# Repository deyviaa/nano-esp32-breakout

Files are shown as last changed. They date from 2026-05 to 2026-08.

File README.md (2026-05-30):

# 🛠️ ArdNanoESP32 DevBoard

> *A compact, feature-packed carrier board for the Arduino Nano ESP32 — bridging the gap between bare breadboard chaos and a polished development kit.*

---

## 📖 Overview

This project is a custom-designed **PCB carrier board** built around the **Arduino Nano ESP32** (dual-core Xtensa LX7, Wi-Fi + BLE). Sized to an approximate **iPhone footprint**, the board is designed as an intermediate prototyping platform with a philosophy of **hardware-level safety** ("student-proofing") — all peripherals are wired with protection resistors, clean logic states, and deliberate design choices baked in at the schematic level.

The board seats the Nano ESP32 in ZIF-style socket headers and exposes every GPIO to parallel jumper pin headers for external breadboard connectivity, while also integrating a full suite of on-board peripherals ready for immediate use.

**Current Status:**

```
✅ Schematic design — Complete & verified
✅ Component footprints — All assigned & resolved
✅ Git version control — Initialized (cross-platform)
🔄 PCB Layout & Routing — In Progress
⬜ Gerber Generation & Fab — Pending
⬜ Assembly & Bring-up — Pending
```

---

## ⚡ Power Architecture

The board runs two accessible power rails sourced from the Nano ESP32's onboard regulators:

| Rail | Source | Purpose |
|---|---|---|
| **5V** | `VUSB` | WS2812B LED, raw power header |
| **3.3V** | Nano onboard LDO | All logic peripherals, GPIO I/O, I2C bus |
| **GND** | Common ground | Shared reference for all rails |

All power rails are broken out to dedicated 4-pin headers on the board edge for external use.

---

## 🧩 Peripheral Map

```
┌─────────────────────────────────────────────────────────┐
│               Arduino Nano ESP32 Carrier Board           │
│                                                         │
│  ┌──────────────┐     ┌─────────────┐                   │
│  │ Nano ESP32   │     │  4x LEDs    │ ── 1kΩ CLR ── GPIO │
│  │  (socketed)  │     │  4x Buttons │ ── 10kΩ PD ── GPIO │
│  └──────────────┘     │  4x Switches│ ── 1kΩ SER ── GPIO │
│                        └─────────────┘                   │
│  ┌──────────────┐     ┌─────────────┐                   │
│  │  WS2812B     │     │  Qwiic/     │                   │
│  │  RGB LED     │     │  STEMMA QT  │ ── SDA(A4)/SCL(A5) │
│  │  (5V + 470Ω) │     │  JST-SH 4P  │ ── 4.7kΩ pull-ups  │
│  └──────────────┘     └─────────────┘                   │
│  ┌──────────────┐     ┌─────────────┐                   │
│  │  Alps RK09K  │     │  12mm Piezo │                   │
│  │  Rotary Pot  │     │  Buzzer     │ ── SW mute ── GPIO  │
│  │  (VDiv/A0)   │     │  (220Ω buf) │                   │
│  └──────────────┘     └─────────────┘                   │
└─────────────────────────────────────────────────────────┘
```

---

## 🔌 Peripheral Specifications

### 💡 LEDs × 4
- Generic standard LEDs, **active-high**
- **1kΩ** current-limiting resistors in series
- Clean GPIO drive, no floating states

### 🔘 Push Buttons × 4
- Momentary tactile switches
- **10kΩ pull-down** resistors → guaranteed `LOW` at rest
- No debounce hardware (handle in firmware or use `INPUT_PULLUP`)

### 🎚️ Slide Switches × 4 (Stateful GPIO Inputs)
- **SS12D00G-G3** SPDT Slide Switches (2.54mm pitch)
- Hard-wired: Pin 1 → 3.3V, Pin 3 → GND, Pin 2 → MCU
- **1kΩ series resistor** between common and GPIO — prevents a dead short if pin is accidentally configured as `OUTPUT LOW`
- ⚠️ *Avoid routing these to ESP32 strapping pins (GPIO0, GPIO3, GPIO45, GPIO46)*

### 🌈 WS2812B Addressable RGB LED
- **5050** form factor, driven from **VUSB (5V)** rail
- **100nF decoupling cap** placed physically adjacent to VDD/GND
- Data driven by 3.3V GPIO through **470Ω series resistor** (signal protection + level tolerance)
- `DOUT` left unconnected — ready for future LED chain expansion

### 🔁 Qwiic / STEMMA QT Connector (I2C)
- **JST-SH SM04B-SRSS-TB**, 1.0mm pitch, 4-pin
- Industry-standard pinout: `GND | 3V3 | SDA | SCL`
- Routed to hardware I2C: **SDA → A4**, **SCL → A5**
- **Two 4.7kΩ pull-up resistors** on SDA and SCL to 3.3V (open-drain compliant)
- Compatible with the entire Sparkfun/Adafruit Qwiic/STEMMA QT ecosystem

### 🎛️ Rotary Potentiometer
- **Alps RK09K** 9mm single-gang
- Wired as a safe voltage divider: Pin 1 → 3.3V, Pin 3 → GND, Wiper → Analog GPIO (A0–A7)
- Footprint includes 2 mechanical snap-in anchor pads for PCB stability

### 🔊 Piezo Buzzer
- **12mm PCB-mount** piezo, standard 7.62mm through-hole pitch
- **220Ω buffer resistor** on signal line
- **Hardware mute switch** (SS12D00 SPDT): one throw connects signal → buzzer positive; mute position leaves the throw floating (no drain-to-GND waste)

---

## 🗂️ Schematic Hierarchy

The project uses a hierarchical schematic structure in KiCad (4 sheets):

| Sheet | File | Contents |
|---|---|---|
| `/` | `ArdNanoESP32_DevBoard.kicad_sch` | Top-level hierarchy |
| `/MCU_Pins_Sockets/` | `MCU_Pins_Sockets.kicad_sch` | Nano ESP32 socket + jumper headers |
| `/PowerRails/` | `PowerRails.kicad_sch` | VUSB, 3V3, GND breakout headers |
| `/Peripherals/` | `Peripherals.kicad_sch` | All on-board peripherals |

---

## 🔧 KiCad Footprint Notes & Resolutions

Several non-obvious footprint decisions were made to match real-world, off-the-shelf components:

| Component | Footprint Assigned | Reason |
|---|---|---|
| SS12D00G-G3 Switches | `PinHeader_1x03_P2.54mm_Vertical` | Amazon-sourced units have **2.54mm pitch** (not standard 2mm) |
| Slide Switch Symbol | Generic `SW_SPDT` | Replaced Wuerth proprietary symbol — Pin 2 must be common to prevent 3V3↔GND short |
| JST-SH I2C Connector | `JST_SH_SM04B-SRSS-TB_1x04-1MP_P1.00mm_Horizontal` | Standard Qwiic/STEMMA 1.0mm pitch |
| Piezo Buzzer | `Buzzer_12x9.5mm_CR2032_Vertical` | Matches 7.62mm THT pin spacing |
| Alps Potentiometer | `Potentiometer_Alps_RK09K_Single_Vertical` | 3 signal pins + 2 mechanical anchor pads |
| Resistors (THT) | `R_Axial_DIN0207_L6.3mm_D2.5mm_P10.16mm_Horizontal` | Matches physical inventory |
| Resistors (SMD) | `R_0603_1608Metric_Pad1.05x0.95mm_HandSolder` | Hand-solder pad relief |

---

## 🌿 Git Workflow & Version Control

The repo is structured for **cross-platform KiCad development** (Windows PC ↔ MacBook Air).

### `.gitignore` covers:
```
# KiCad auto-generated / user-specific files
*.kicad_prl        # Per-user UI layout state
fp-info-cache      # Local footprint cache (rebuilt automatically)
*-bak              # KiCad backup files
*.lck              # Lock files (open-file indicators)
*_autosave-*       # Crash recovery autosaves
```

### ⚠️ Critical Workflow Rule

KiCad `.kicad_sch` and `.kicad_pcb` files are **binary-adjacent** — they do not merge cleanly. Follow this loop **strictly**:

```
┌─────────────────────────────────────────────┐
│                                             │
│   1. git pull  ← ALWAYS before opening     │
│   2. Open KiCad & do work                  │
│   3. Close KiCad (flushes file writes)     │
│   4. git add / commit / push               │
│                                             │
│   ❌ Never leave files open across machines │
│   ❌ Never commit while KiCad is open       │
│                                             │
└─────────────────────────────────────────────┘
```

---

## 🧰 Tools & Software

| Tool | Version | Purpose |
|---|---|---|
| **KiCad** | 8.0.x | Schematic capture & PCB layout |
| **Git** | Any | Version control |
| **Arduino IDE / PlatformIO** | Latest | Firmware development |

---

## 📐 Design Constraints

- **Target Form Factor:** ~iPhone footprint (≈ 71mm × 150mm)
- **MCU:** Arduino Nano ESP32 (seated, not soldered)
- **Logic Level:** 3.3V throughout
- **Power Input:** USB via Nano ESP32 onboard USB-C

---

## 🚧 Roadmap

- [x] Schematic capture (all 4 sheets)
- [x] ERC pass — no errors
- [x] Footprint assignment & verification
- [x] Git repo initialization + `.gitignore`
- [ ] PCB layout — component placement
- [ ] PCB routing — all nets
- [ ] DRC pass — no errors
- [ ] 3D model review
- [ ] Gerber generation
- [ ] PCB fabrication (JLCPCB / PCBWay)
- [ ] Board bring-up & hardware testing
- [ ] Firmware examples / demo sketches

---

## 📄 License

*To be determined.*

---

> *Designed in KiCad. Iterated on breadboards. Built to survive students.*

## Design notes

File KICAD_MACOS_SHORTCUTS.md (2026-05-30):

# KiCad macOS Shortcuts

A comprehensive and organized list of macOS shortcuts and commands for KiCad, broken down by application module.

## 3D Viewer

| Context | Action | Shortcut |
|---|---|---|
| Control | 3 D Viewer. Control |  |
| Control | Attribute Dnp | D |
| Control | Attribute Not In Posfile | P |
| Control | Attributes Other | V |
| Control | Attributes S M D | S |
| Control | Attributes T H T | T |
| Control | Copy To Clipboard |  |
| Control | Export Image |  |
| Control | Flip View | F |
| Control | Home View | Home |
| Control | Material C A D |  |
| Control | Material Diffuse |  |
| Control | Material Normal |  |
| Control | Move Down | Down |
| Control | Move Left | Left |
| Control | Move Right | Right |
| Control | Move Up | Up |
| Control | No Grid |  |
| Control | Pivot Center | Space |
| Control | Reload Board |  |
| Control | Rotate Xclockwise |  |
| Control | Rotate Xcounterclockwise |  |
| Control | Rotate Yclockwise |  |
| Control | Rotate Ycounterclockwise |  |
| Control | Rotate Zclockwise | Shift+R |
| Control | Rotate Zcounterclockwise | R |
| Control | Show10Mm Grid |  |
| Control | Show1Mm Grid |  |
| Control | Show2 5Mm Grid |  |
| Control | Show5Mm Grid |  |
| Control | Show Bounding Boxes |  |
| Control | Show Layers Manager |  |
| Control | Show Navigator |  |
| Control | Toggle Ortho |  |
| Control | Toggle Raytacing |  |
| Control | View Back | Shift+Y |
| Control | View Bottom | Shift+Z |
| Control | View Front | Y |
| Control | View Left | Shift+X |
| Control | View Right | X |
| Control | View Top | Z |

## Common Shortcuts

| Context | Action | Shortcut |
|---|---|---|
| API | Plugins Reload |  |
| Checker | Exclude Marker |  |
| Checker | Next Marker |  |
| Checker | Prev Marker |  |
| Control | Activate Point Editor |  |
| Control | Add Library |  |
| Control | Center Contents |  |
| Control | Center Justify |  |
| Control | Center Selection |  |
| Control | Collapse All |  |
| Control | Cursor45 Crosshairs |  |
| Control | Cursor Click | Return |
| Control | Cursor Dbl Click | End |
| Control | Cursor Down | Down |
| Control | Cursor Down Fast | Cmd+Down |
| Control | Cursor Full Crosshairs |  |
| Control | Cursor Left | Left |
| Control | Cursor Left Fast | Cmd+Left |
| Control | Cursor Right | Right |
| Control | Cursor Right Fast | Cmd+Right |
| Control | Cursor Small Crosshairs |  |
| Control | Cursor Up | Up |
| Control | Cursor Up Fast | Cmd+Up |
| Control | Ddadd Library |  |
| Control | Edit Grid Origin |  |
| Control | Edit Grids |  |
| Control | Expand All |  |
| Control | Grid Fast1 | Option+1 |
| Control | Grid Fast2 | Option+2 |
| Control | Grid Fast Cycle | Option+4 |
| Control | Grid Next | N |
| Control | Grid Preset |  |
| Control | Grid Prev | Shift+N |
| Control | Grid Reset Origin |  |
| Control | Grid Set Origin |  |
| Control | Hide Library Tree |  |
| Control | High Contrast Mode |  |
| Control | High Contrast Mode Cycle | H |
| Control | Imperial Units |  |
| Control | Left Justify |  |
| Control | Library Tree Search | Cmd+L |
| Control | Magnetic Snap Active Layer |  |
| Control | Magnetic Snap All Layers |  |
| Control | Magnetic Snap Toggle | Shift+S |
| Control | Metric Units |  |
| Control | Mils |  |
| Control | New | Cmd+N |
| Control | New Library |  |
| Control | Open | Cmd+O |
| Control | Open Directory |  |
| Control | Open With Text Editor |  |
| Control | Page Settings |  |
| Control | Pan Down | Shift+Down |
| Control | Pan Left | Shift+Left |
| Control | Pan Right | Shift+Right |
| Control | Pan Up | Shift+Up |
| Control | Pin Library |  |
| Control | Plot |  |
| Control | Print | Cmd+P |
| Control | Quit |  |
| Control | Redo Zoom |  |
| Control | Refresh Preview |  |
| Control | Reset Local Coords | Space |
| Control | Revert |  |
| Control | Right Justify |  |
| Control | Save | Cmd+S |
| Control | Save All |  |
| Control | Save As | Cmd+Shift+S |
| Control | Save Copy |  |
| Control | Select Columns |  |
| Control | Show3 D Viewer | Option+3 |
| Control | Show Calculator Tools |  |
| Control | Show Context Menu |  |
| Control | Show Datasheet | D |
| Control | Show Footprint Browser |  |
| Control | Show Footprint Editor |  |
| Control | Show Library Tree |  |
| Control | Show Project Manager |  |
| Control | Show Properties |  |
| Control | Show Symbol Browser |  |
| Control | Show Symbol Editor |  |
| Control | Toggle Bounding Boxes |  |
| Control | Toggle Cursor |  |
| Control | Toggle Grid |  |
| Control | Toggle Grid Overrides | Cmd+Shift+G |
| Control | Toggle Polar Coords |  |
| Control | Toggle Units | Cmd+U |
| Control | Undo Zoom |  |
| Control | Unpin Library |  |
| Control | Update Find |  |
| Control | Update Pcb From Schematic | F8 |
| Control | Update Preferences |  |
| Control | Update Schematic From P C B |  |
| Control | Update Units |  |
| Control | Zoom Center | F4 |
| Control | Zoom Fit Objects | Cmd+Home |
| Control | Zoom Fit Screen | Cmd+0 |
| Control | Zoom Fit Selection |  |
| Control | Zoom In | Cmd++ |
| Control | Zoom In Center |  |
| Control | Zoom In Horizontally |  |
| Control | Zoom In Vertically |  |
| Control | Zoom Out | Cmd+- |
| Control | Zoom Out Center |  |
| Control | Zoom Out Horizontally |  |
| Control | Zoom Out Vertically |  |
| Control | Zoom Preset |  |
| Control | Zoom Redraw | Cmd+R |
| Control | Zoom Tool | Cmd+F5 |
| Embed | Embeded File |  |
| Embed | Extract File |  |
| Embed | Remove File |  |
| Groups | Group Properties |  |
| Groups | Select New Group Member |  |
| Interactive | Add To Group |  |
| Interactive | Cancel |  |
| Interactive | Copy | Cmd+C |
| Interactive | Copy As Text | Cmd+Shift+C |
| Interactive | Cut | Cmd+X |
| Interactive | Cycle Arc Edit Mode | Cmd+Space |
| Interactive | Delete | Back |
| Interactive | Delete Tool |  |
| Interactive | Duplicate | Cmd+D |
| Interactive | Find | Cmd+F |
| Interactive | Find And Replace | Cmd+Option+F |
| Interactive | Find Next | F3 |
| Interactive | Find Next Marker | Cmd+Shift+F3 |
| Interactive | Find Previous | Shift+F3 |
| Interactive | Finish | End |
| Interactive | Group |  |
| Interactive | Group Enter |  |
| Interactive | Group Leave |  |
| Interactive | Measure Tool | Cmd+Shift+M |
| Interactive | Paste | Cmd+V |
| Interactive | Paste Special | Cmd+Shift+V |
| Interactive | Redo | Cmd+Shift+Z |
| Interactive | Remove From Group |  |
| Interactive | Replace All |  |
| Interactive | Replace And Find Next |  |
| Interactive | Search | Cmd+G |
| Interactive | Select All | Cmd+A |
| Interactive | Select Set Lasso |  |
| Interactive | Select Set Rect |  |
| Interactive | Undo | Cmd+Z |
| Interactive | Ungroup |  |
| Interactive | Unselect All | Cmd+Shift+A |
| Interactive | Update Menu |  |
| InteractivePicker | Picker Sub Tool |  |
| InteractivePicker | Picker Tool |  |
| InteractiveSelection | Common. Interactive Selection |  |
| InteractiveSelection | Rows |  |
| InteractiveSelection | Select Columns |  |
| InteractiveSelection | Select Table |  |
| InteractiveSelection | Clear |  |
| InteractiveSelection | Cursor |  |
| InteractiveSelection | Reselect Item |  |
| InteractiveSelection | Select Item |  |
| InteractiveSelection | Select Items |  |
| InteractiveSelection | Selection Menu |  |
| InteractiveSelection | Selection Tool |  |
| InteractiveSelection | Unselect Item |  |
| InteractiveSelection | Unselect Items |  |
| SuiteControl | About |  |
| SuiteControl | Configure Paths |  |
| SuiteControl | Donate |  |
| SuiteControl | Get Involved |  |
| SuiteControl | Getting Started |  |
| SuiteControl | Help |  |
| SuiteControl | List Hot Keys | Cmd+F1 |
| SuiteControl | Open Preferences | Cmd+, |
| SuiteControl | Report Bug |  |
| SuiteControl | Show Design B Lock Lib Table |  |
| SuiteControl | Show Footprint Lib Table |  |
| SuiteControl | Show Symbol Lib Table |  |
| TableEditor | Add Col After |  |
| TableEditor | Add Col Before |  |
| TableEditor | Add Row Above |  |
| TableEditor | Add Row Below |  |
| TableEditor | Delete Columns |  |
| TableEditor | Delete Rows |  |
| TableEditor | Export Table C S V |  |
| TableEditor | Merge Cells |  |
| TableEditor | Unmerge Cell |  |

## Schematic Editor (Eeschema)

| Context | Action | Shortcut |
|---|---|---|
| Align | Align Bottom |  |
| Align | Align Center X |  |
| Align | Align Center Y |  |
| Align | Align Left |  |
| Align | Align Right |  |
| Align | Align Top |  |
| AlignToGrid | Eeschema. Align To Grid |  |
| EditorControl | Add Variant |  |
| EditorControl | Angle Snap Mode Changed |  |
| EditorControl | Annotate |  |
| EditorControl | Annotate Automatically |  |
| EditorControl | Assign Footprints |  |
| EditorControl | Clear Highlight | ~ |
| EditorControl | Dd Add Image |  |
| EditorControl | Dd Append File |  |
| EditorControl | Dd Import Graphics |  |
| EditorControl | Draw Sheet On Clipboard |  |
| EditorControl | Edit Lib Symbol With Symbol Editor | Cmd+Shift+E |
| EditorControl | Edit Page Number |  |
| EditorControl | Edit Symbol Fields |  |
| EditorControl | Edit Symbol Library Links |  |
| EditorControl | Edit Variant Description |  |
| EditorControl | Edit With Symbol Editor | Cmd+E |
| EditorControl | Export Netlist |  |
| EditorControl | Export Symbols To Library |  |
| EditorControl | Generate B O M |  |
| EditorControl | Generate B O M External |  |
| EditorControl | Generate B O M Legacy |  |
| EditorControl | Highlight Net | ` |
| EditorControl | Highlight Net Tool |  |
| EditorControl | Import F P Assignments |  |
| EditorControl | Import Graphics | Cmd+Shift+F |
| EditorControl | Import Non Kicad Schematic |  |
| EditorControl | Increment Annotations |  |
| EditorControl | Line Mode45 |  |
| EditorControl | Line Mode Free |  |
| EditorControl | Line Mode Next | Shift+Space |
| EditorControl | Line Mode Orthonal |  |
| EditorControl | Mark Sim Exclusions |  |
| EditorControl | Next Net Item | Tab |
| EditorControl | Next Unit |  |
| EditorControl | Previous Net Item | Shift+Tab |
| EditorControl | Previous Unit |  |
| EditorControl | Remap Symbols |  |
| EditorControl | Remove Variant |  |
| EditorControl | Rescue Symbols |  |
| EditorControl | Restart Move |  |
| EditorControl | Save Curr Sheet Copy As |  |
| EditorControl | Schematic Setup |  |
| EditorControl | Select On P C B |  |
| EditorControl | Set D N P |  |
| EditorControl | Set Exclude From B O M |  |
| EditorControl | Set Exclude From Board |  |
| EditorControl | Set Exclude From Simulation |  |
| EditorControl | Show Directive Labels |  |
| EditorControl | Show E R C Errors |  |
| EditorControl | Show E R C Exclusions |  |
| EditorControl | Show E R C Warnings |  |
| EditorControl | Show Hidden Fields |  |
| EditorControl | Show Hidden Pins |  |
| EditorControl | Show Net Navigator |  |
| EditorControl | Show Operating Point Currents |  |
| EditorControl | Show Operating Point Voltages |  |
| EditorControl | Show Pcb New |  |
| EditorControl | Show Simulator |  |
| EditorControl | Toggle Pin Alt Icons |  |
| EditorControl | Update Net Highlighting |  |
| EditorTool | Show Hierarchy | Cmd+H |
| InspectionTool | Check Symbol |  |
| InspectionTool | Diff Symbol |  |
| InspectionTool | Run E R C |  |
| InspectionTool | Show Bus Syntax Help |  |
| Interactive | Decrement Primary |  |
| Interactive | Decrement Secondary |  |
| Interactive | Increment |  |
| Interactive | Increment Primary |  |
| Interactive | Increment Secondary |  |
| InteractiveDrawing | Autoplace All Sheet Pins |  |
| InteractiveDrawing | Close Outline |  |
| InteractiveDrawing | Delete Last Point |  |
| InteractiveDrawing | Draw Arc |  |
| InteractiveDrawing | Draw Bezier |  |
| InteractiveDrawing | Draw Circle |  |
| InteractiveDrawing | Draw Rectangle |  |
| InteractiveDrawing | Draw Rule Area |  |
| InteractiveDrawing | Draw Sheet | S |
| InteractiveDrawing | Draw Sheet From Design Block |  |
| InteractiveDrawing | Draw Sheet From File |  |
| InteractiveDrawing | Draw Table |  |
| InteractiveDrawing | Draw Text Box |  |
| InteractiveDrawing | Import Sheet |  |
| InteractiveDrawing | Place Bus Wire Entry | Z |
| InteractiveDrawing | Place Class Label |  |
| InteractiveDrawing | Place Design Block | Shift+B |
| InteractiveDrawing | Place Global Label | Cmd+L |
| InteractiveDrawing | Place Hierarchical Label | H |
| InteractiveDrawing | Place Image |  |
| InteractiveDrawing | Place Junction | J |
| InteractiveDrawing | Place Label | L |
| InteractiveDrawing | Place Linked Design Block |  |
| InteractiveDrawing | Place Next Symbol Unit |  |
| InteractiveDrawing | Place No Connect | Q |
| InteractiveDrawing | Place Power Symbol | P |
| InteractiveDrawing | Place Schematic Text | T |
| InteractiveDrawing | Place Sheet Pin |  |
| InteractiveDrawing | Place Symbol | A |
| InteractiveDrawing | Save To Linked Design Block |  |
| InteractiveDrawing | Sync All Sheets Pins |  |
| InteractiveDrawing | Sync Sheet Pins |  |
| InteractiveDrawingLineWireBus | Draw Buses | B |
| InteractiveDrawingLineWireBus | Draw Lines | I |
| InteractiveDrawingLineWireBus | Draw Wires | W |
| InteractiveDrawingLineWireBus | Switch Posture | / |
| InteractiveDrawingLineWireBus | Undo Last Segment | Back |
| InteractiveDrawingLineWireBus | Unfold Bus | C |
| InteractiveEdit | Assign Netclass |  |
| InteractiveEdit | Autoplace Fields | O |
| InteractiveEdit | Break Wire |  |
| InteractiveEdit | Change Symbol |  |
| InteractiveEdit | Change Symbols |  |
| InteractiveEdit | Cleanup Sheet Pins |  |
| InteractiveEdit | Convert Stacked Pins |  |
| InteractiveEdit | Edit Footprint | F |
| InteractiveEdit | Edit Reference | U |
| InteractiveEdit | Edit Text And Graphics |  |
| InteractiveEdit | Edit Value | V |
| InteractiveEdit | Explode Stacked Pin |  |
| InteractiveEdit | Find Net In Inspector |  |
| InteractiveEdit | Mirror H | X |
| InteractiveEdit | Mirror V | Y |
| InteractiveEdit | Pin Table |  |
| InteractiveEdit | Properties | E |
| InteractiveEdit | Repeat Draw Item | F1 |
| InteractiveEdit | Rotate C C W | R |
| InteractiveEdit | Rotate C W | Shift+R |
| InteractiveEdit | Slice |  |
| InteractiveEdit | Swap | Option+S |
| InteractiveEdit | Swap Pin Labels |  |
| InteractiveEdit | Swap Pins |  |
| InteractiveEdit | Swap Unit Labels |  |
| InteractiveEdit | Symbol Properties |  |
| InteractiveEdit | To C Label |  |
| InteractiveEdit | To G Label |  |
| InteractiveEdit | To H Label |  |
| InteractiveEdit | To Label |  |
| InteractiveEdit | To Text |  |
| InteractiveEdit | To Text Box |  |
| InteractiveEdit | Toggle De Morgan |  |
| InteractiveEdit | Update Symbol |  |
| InteractiveEdit | Update Symbols |  |
| InteractiveMove | Drag | G |
| InteractiveMove | Move | M |
| InteractiveSelection | Select Connection | Cmd+4 |
| InteractiveSelection | Select Node | Option+3 |
| InteractiveSelection | Sync Selection |  |
| NavigateTool | Back | Option+Left |
| NavigateTool | Change Sheet |  |
| NavigateTool | Enter Sheet |  |
| NavigateTool | Forward | Option+Right |
| NavigateTool | Leave Sheet | Option+Back |
| NavigateTool | Next | PgDn |
| NavigateTool | Previous | PgUp |
| NavigateTool | Up | Option+Up |
| PinEditing | Push Pin Length |  |
| PinEditing | Push Pin Name Size |  |
| PinEditing | Push Pin Num Size |  |
| PointEditor | Add Corner |  |
| PointEditor | Remove Corner |  |
| RemoteSymbols | Show Panel |  |
| SchDesignBlockControl | Delete Design Block |  |
| SchDesignBlockControl | Edit Design Block Properties |  |
| SchDesignBlockControl | Save Selection As Design Block |  |
| SchDesignBlockControl | Save Sheet As Design Block |  |
| SchDesignBlockControl | Show Design Block Panel |  |
| SchDesignBlockControl | Update Design Block From Selection |  |
| SchDesignBlockControl | Update Design Block From Sheet |  |
| Simulation | Edit User Defined Signals |  |
| Simulation | New Analysis Tab | Cmd+N |
| Simulation | Open Workbook | Cmd+O |
| Simulation | Probe | Shift+P |
| Simulation | Run Simulation | R |
| Simulation | Save Workbook | Cmd+S |
| Simulation | Save Workbook As | Cmd+Shift+S |
| Simulation | Show Netlist |  |
| Simulation | Sim Analysis Properties |  |
| Simulation | Stop Simulation |  |
| Simulation | Tune | Shift+T |
| Simulator | Export C S V |  |
| Simulator | Export P N G |  |
| Simulator | Export Plot To Schematic |  |
| Simulator | Export To Clipboard |  |
| Simulator | Toggle Dark Mode Plots |  |
| Simulator | Toggle Dotted Secondary |  |
| Simulator | Toggle Legend |  |
| Simulator | Toggle Sim Console |  |
| Simulator | Toggle Sim Side Panel |  |
| SymbolDrawing | Draw Symbol Lines |  |
| SymbolDrawing | Draw Symbol Polygon |  |
| SymbolDrawing | Draw Symbol Text Box |  |
| SymbolDrawing | Place Symbol Anchor |  |
| SymbolDrawing | Place Symbol Pin | P |
| SymbolDrawing | Place Symbol Text |  |
| SymbolLibraryControl | Add Symbol To Schematic |  |
| SymbolLibraryControl | Copy Symbol |  |
| SymbolLibraryControl | Cut Symbol |  |
| SymbolLibraryControl | Delete Symbol |  |
| SymbolLibraryControl | Derive From Existing Symbol |  |
| SymbolLibraryControl | Duplicate Symbol |  |
| SymbolLibraryControl | Edit Symbol |  |
| SymbolLibraryControl | Export Symbol |  |
| SymbolLibraryControl | Export Symbol As S V G |  |
| SymbolLibraryControl | Export Symbol View |  |
| SymbolLibraryControl | Flatten Symbol |  |
| SymbolLibraryControl | Import Symbol |  |
| SymbolLibraryControl | New Symbol | Cmd+N |
| SymbolLibraryControl | Next Symbol |  |
| SymbolLibraryControl | Paste Symbol |  |
| SymbolLibraryControl | Previous Symbol |  |
| SymbolLibraryControl | Rename Footprint |  |
| SymbolLibraryControl | Save Library As | Cmd+Shift+S |
| SymbolLibraryControl | Save Symbol As |  |
| SymbolLibraryControl | Save Symbol Copy As |  |
| SymbolLibraryControl | Show Electrical Types |  |
| SymbolLibraryControl | Show Hidden Fields |  |
| SymbolLibraryControl | Show Hidden Pins |  |
| SymbolLibraryControl | Show Library Fields Table |  |
| SymbolLibraryControl | Show Pin Numbers |  |
| SymbolLibraryControl | Show Related Library Fields Table |  |
| SymbolLibraryControl | Toggle Synced Pins Mode |  |
| SymbolLibraryControl | Update Symbol Fields |  |

## Gerber Viewer (Gerbview)

| Context | Action | Shortcut |
|---|---|---|
| Control | Clear All Layers |  |
| Control | Clear Layer |  |
| Control | Dcode Display | D |
| Control | Export To Pcbnew |  |
| Control | Flashed Display Outlines | F |
| Control | Flip Gerber View |  |
| Control | Highlight Attribute |  |
| Control | Highlight Clear |  |
| Control | Highlight Component |  |
| Control | Highlight D Code |  |
| Control | Highlight Net |  |
| Control | Layer Changed |  |
| Control | Layer Next | PgDn |
| Control | Layer Prev | PgUp |
| Control | Load Gerb Files |  |
| Control | Load Zip File |  |
| Control | Move Layer Down | - |
| Control | Move Layer Up | + |
| Control | Negative Object Display |  |
| Control | Open Autodetected |  |
| Control | Open Drill File |  |
| Control | Open Gerber |  |
| Control | Open Job File |  |
| Control | Open Zip File |  |
| Control | Polygons Display Outlines | P |
| Control | Reload All Layers |  |
| Control | Toggle Force Opacity Mode |  |
| Control | Toggle Layer Manager |  |
| Control | Toggle X O R Mode |  |
| Inspection | Show D Codes |  |
| Inspection | Show Source |  |

## Project Manager

| Context | Action | Shortcut |
|---|---|---|
| Control | Open Project Directory |  |
| Control | Archive Project |  |
| Control | Close Project |  |
| Control | Convert Image | Cmd+B |
| Control | Edit Drawing Sheet | Cmd+Y |
| Control | Edit Footprints | Cmd+F |
| Control | Edit Other P C B |  |
| Control | Edit Other Sch |  |
| Control | Edit P C B | Cmd+P |
| Control | Edit Schematic | Cmd+E |
| Control | Edit Symbols | Cmd+L |
| Control | Load Project |  |
| Control | New From Repository |  |
| Control | New Jobs |  |
| Control | New Project | Cmd+N |
| Control | Open Demo Project |  |
| Control | Open Jobset |  |
| Control | Open Project | Cmd+O |
| Control | Open Text Editor |  |
| Control | Plugin Content Manager | Cmd+M |
| Control | Restore Local History |  |
| Control | Show Calculator |  |
| Control | Show Local History |  |
| Control | Unarchive Project |  |
| Control | View Dropped Gerbers |  |
| Control | View Gerbers | Cmd+G |

## PCB Editor (Pcbnew)

| Context | Action | Shortcut |
|---|---|---|
| AlignAndDistribute | Align Bottom |  |
| AlignAndDistribute | Align Center X |  |
| AlignAndDistribute | Align Center Y |  |
| AlignAndDistribute | Align Left |  |
| AlignAndDistribute | Align Right |  |
| AlignAndDistribute | Align Top |  |
| AlignAndDistribute | Distribute Horizontally Centers |  |
| AlignAndDistribute | Distribute Horizontally Gaps |  |
| AlignAndDistribute | Distribute Vertically Centers |  |
| AlignAndDistribute | Distribute Vertically Gaps |  |
| Array | Create Array | Cmd+T |
| Autoplacer | Autoplace Offboard |  |
| Autoplacer | Autoplace Selected |  |
| Control | Dd Append Board |  |
| Control | Change Track Layer Next | Cmd++ |
| Control | Change Track Layer Prev | Cmd+- |
| Control | Dd Import Footprint |  |
| Control | Flip Board |  |
| Control | Fp Auto Zoom |  |
| Control | Graphic Outlines |  |
| Control | Hide Dynamic Ratsnest |  |
| Control | Layer Alpha Dec | { |
| Control | Layer Alpha Inc | } |
| Control | Layer Bottom | PgDn |
| Control | Layer Changed |  |
| Control | Layer Inner1 |  |
| Control | Layer Inner10 |  |
| Control | Layer Inner11 |  |
| Control | Layer Inner12 |  |
| Control | Layer Inner13 |  |
| Control | Layer Inner14 |  |
| Control | Layer Inner15 |  |
| Control | Layer Inner16 |  |
| Control | Layer Inner17 |  |
| Control | Layer Inner18 |  |
| Control | Layer Inner19 |  |
| Control | Layer Inner2 |  |
| Control | Layer Inner20 |  |
| Control | Layer Inner21 |  |
| Control | Layer Inner22 |  |
| Control | Layer Inner23 |  |
| Control | Layer Inner24 |  |
| Control | Layer Inner25 |  |
| Control | Layer Inner26 |  |
| Control | Layer Inner27 |  |
| Control | Layer Inner28 |  |
| Control | Layer Inner29 |  |
| Control | Layer Inner3 |  |
| Control | Layer Inner30 |  |
| Control | Layer Inner4 |  |
| Control | Layer Inner5 |  |
| Control | Layer Inner6 |  |
| Control | Layer Inner7 |  |
| Control | Layer Inner8 |  |
| Control | Layer Inner9 |  |
| Control | Layer Next | + |
| Control | Layer Pair Preset Cycle | Shift+V |
| Control | Layer Prev | - |
| Control | Layer Toggle | V |
| Control | Layer Top | PgUp |
| Control | Local Ratsnest Tool |  |
| Control | Net Color Mode |  |
| Control | Next Footprint |  |
| Control | Pad Display Mode |  |
| Control | Previous Footprint |  |
| Control | Ratsnest Line Mode |  |
| Control | Ratsnest Mode Cycle |  |
| Control | Rehatch Shapes |  |
| Control | Repair Board |  |
| Control | Show Layers Manager |  |
| Control | Show Net Inspector |  |
| Control | Show Pad Numbers |  |
| Control | Show Python Console |  |
| Control | Show Ratsnest |  |
| Control | Text Outlines |  |
| Control | Track Display Mode | K |
| Control | Update Local Ratsnest |  |
| Control | Via Display Mode |  |
| Control | Zone Display Disable |  |
| Control | Zone Display Enable |  |
| Control | Zone Display Outlines |  |
| Control | Zone Display Tesselation |  |
| Control | Zone Display Toggle |  |
| Control | Zones Manager |  |
| Convert | Convert To Arc |  |
| Convert | Convert To Keepout |  |
| Convert | Convert To Lines |  |
| Convert | Convert To Poly |  |
| Convert | Convert To Tracks |  |
| Convert | Convert To Zone |  |
| Convert | Outset Items |  |
| DRCTool | Run D R C |  |
| DRETool | Drc Rule Editor |  |
| EditorControl | Edit Fp In Fp Editor | Cmd+E |
| EditorControl | Edit Lib Fp In Fp Editor | Cmd+Shift+E |
| EditorControl | Angle Snap Mode Changed |  |
| EditorControl | Append Board |  |
| EditorControl | Assign Netclass |  |
| EditorControl | Auto Track Width |  |
| EditorControl | Board Setup |  |
| EditorControl | Clear Highlight | ~ |
| EditorControl | Collect3 D Models |  |
| EditorControl | Drill Origin |  |
| EditorControl | Drill Reset Origin |  |
| EditorControl | Drill Set Origin |  |
| EditorControl | Export Footprint Associations |  |
| EditorControl | Export Footprints |  |
| EditorControl | Export Gen C A D |  |
| EditorControl | Export Hyperlynx |  |
| EditorControl | Export I D F |  |
| EditorControl | Export S T E P |  |
| EditorControl | Export Specctra D S N |  |
| EditorControl | Export V R M L |  |
| EditorControl | Generate B O M |  |
| EditorControl | Generate D356 File |  |
| EditorControl | Generate Drill Files |  |
| EditorControl | Generate Gerbers |  |
| EditorControl | Generate I P C2581 File |  |
| EditorControl | Generate O D B P P File |  |
| EditorControl | Generate Pos File |  |
| EditorControl | Generate Report File |  |
| EditorControl | Hide Net |  |
| EditorControl | Highlight Item |  |
| EditorControl | Highlight Net | ` |
| EditorControl | Highlight Net Selection |  |
| EditorControl | Import Netlist |  |
| EditorControl | Import Specctra Session |  |
| EditorControl | Line Mode45 |  |
| EditorControl | Line Mode Free |  |
| EditorControl | Line Mode Next | Shift+Space |
| EditorControl | Line Mode Orthonal |  |
| EditorControl | Lock |  |
| EditorControl | Open Non Kicad Board |  |
| EditorControl | Place Footprint | A |
| EditorControl | Rescue Autosave |  |
| EditorControl | Show Eeschema |  |
| EditorControl | Show Net |  |
| EditorControl | Toggle Last Net Highlight |  |
| EditorControl | Toggle Lock | L |
| EditorControl | Toggle Net Highlight | Option+` |
| EditorControl | Track Via Size Changed |  |
| EditorControl | Track Width Dec | Shift+W |
| EditorControl | Track Width Inc | W |
| EditorControl | Unlock |  |
| EditorControl | Via Size Dec | \ |
| EditorControl | Via Size Inc | ' |
| EditorControl | Zone Duplicate |  |
| EditorControl | Zone Merge |  |
| EditorControl | Zone Priority Lower |  |
| EditorControl | Zone Priority Move To Bottom |  |
| EditorControl | Zone Priority Move To Top |  |
| EditorControl | Zone Priority Raise |  |
| FpWizard | Export Fp To Editor |  |
| FpWizard | Reset Wizard Prms |  |
| FpWizard | Select Next Wizard Page |  |
| FpWizard | Select Previous Wizard Page |  |
| FpWizard | Show Wizards |  |
| Generator | Gen Cacnel Edit |  |
| Generator | Gen Finish Edit |  |
| Generator | Gen Remove |  |
| Generator | Gen Start Edit |  |
| Generator | Gen Update Edit |  |
| Generator | Regenerate All |  |
| Generator | Regenerate All Tuning |  |
| Generator | Regenerate Selected |  |
| Generator | Show Manager |  |
| GlobalEdit | Change Footprint |  |
| GlobalEdit | Change Footprints |  |
| GlobalEdit | Cleanup Graphics |  |
| GlobalEdit | Cleanup Tracks And Vias |  |
| GlobalEdit | Edit Teardrops |  |
| GlobalEdit | Edit Text And Graphics |  |
| GlobalEdit | Edit Tracks And Vias |  |
| GlobalEdit | Global Deletions |  |
| GlobalEdit | Migrate3 D Models |  |
| GlobalEdit | Remove Unused Pads |  |
| GlobalEdit | Swap Layers |  |
| GlobalEdit | Update Footprint |  |
| GlobalEdit | Update Footprints |  |
| InspectionTool | Diff Footprint |  |
| InspectionTool | Inspect Clearance |  |
| InspectionTool | Inspect Constraints |  |
| InspectionTool | Show Board Statistics |  |
| InspectionTool | Show Footprint Associations |  |
| InteractiveDrawing | Aligned Dimension |  |
| InteractiveDrawing | Apply Design Block Layout |  |
| InteractiveDrawing | Arc | Cmd+Shift+A |
| InteractiveDrawing | Arc Posture | / |
| InteractiveDrawing | Barcode |  |
| InteractiveDrawing | Bezier | Cmd+Shift+B |
| InteractiveDrawing | Center Dimension |  |
| InteractiveDrawing | Change Dimension Arrows |  |
| InteractiveDrawing | Circle | Cmd+Shift+C |
| InteractiveDrawing | Close Outline |  |
| InteractiveDrawing | Dd Import Graphics |  |
| InteractiveDrawing | Dec Width | Cmd+- |
| InteractiveDrawing | Delete Last Point | Back |
| InteractiveDrawing | Draw Table |  |
| InteractiveDrawing | Graphic Polygon | Cmd+Shift+P |
| InteractiveDrawing | Inc Width | Cmd++ |
| InteractiveDrawing | Leader |  |
| InteractiveDrawing | Line | Cmd+Shift+L |
| InteractiveDrawing | Orthogonal Dimension | Cmd+Shift+H |
| InteractiveDrawing | Place Characteristics |  |
| InteractiveDrawing | Place Design Block | Shift+B |
| InteractiveDrawing | Place Imported Graphics | Cmd+Shift+F |
| InteractiveDrawing | Place Linked Design Block |  |
| InteractiveDrawing | Place Point |  |
| InteractiveDrawing | Place Reference Image |  |
| InteractiveDrawing | Place Stackup |  |
| InteractiveDrawing | Radial Dimension |  |
| InteractiveDrawing | Rectangle |  |
| InteractiveDrawing | Rule Area | Cmd+Shift+K |
| InteractiveDrawing | Save To Linked Design Block |  |
| InteractiveDrawing | Set Anchor | Cmd+Shift+N |
| InteractiveDrawing | Similar Zone | Cmd+Shift+. |
| InteractiveDrawing | Text | Cmd+Shift+T |
| InteractiveDrawing | Textbox |  |
| InteractiveDrawing | Via | Cmd+Shift+X |
| InteractiveDrawing | Zone | Option+Z |
| InteractiveDrawing | Zone Cutout | Shift+C |
| InteractiveEdit | Find Move | T |
| InteractiveEdit | Chamfer Lines |  |
| InteractiveEdit | Change Track Width |  |
| InteractiveEdit | Delete Full | Shift+Del |
| InteractiveEdit | Dogbone Corners |  |
| InteractiveEdit | Duplicate Increment Pads | Cmd+Shift+D |
| InteractiveEdit | Edit Vertices |  |
| InteractiveEdit | Extend Lines |  |
| InteractiveEdit | Fillet Lines |  |
| InteractiveEdit | Fillet Tracks |  |
| InteractiveEdit | Flip | F |
| InteractiveEdit | Heal Shapes |  |
| InteractiveEdit | Intersect Polygons |  |
| InteractiveEdit | Merge Polygons |  |
| InteractiveEdit | Mirror Horiontally |  |
| InteractiveEdit | Mirror Vertically |  |
| InteractiveEdit | Move Corner |  |
| InteractiveEdit | Move Exact | Shift+M |
| InteractiveEdit | Move Midpoint |  |
| InteractiveEdit | Pack And Move Footprints | P |
| InteractiveEdit | Properties | E |
| InteractiveEdit | Rotate Ccw | R |
| InteractiveEdit | Rotate Cw | Shift+R |
| InteractiveEdit | Simplify Polygons |  |
| InteractiveEdit | Skip | Tab |
| InteractiveEdit | Subtract Polygons |  |
| InteractiveEdit | Swap | Option+S |
| InteractiveEdit | Swap Gate Nets |  |
| InteractiveEdit | Swap Pad Nets |  |
| InteractiveMove | Copy With Reference |  |
| InteractiveMove | Move | M |
| InteractiveMove | Move Individually | Cmd+M |
| InteractiveMove | Move With Reference |  |
| InteractiveRouter | Attempt Finish | F |
| InteractiveRouter | Autoroute | Shift+F |
| InteractiveRouter | Break Track |  |
| InteractiveRouter | Cancel Current Item |  |
| InteractiveRouter | Continue From End | Cmd+E |
| InteractiveRouter | Custom Track Via Size | Q |
| InteractiveRouter | Cycle Router Mode |  |
| InteractiveRouter | Diff Pair | 6 |
| InteractiveRouter | Diff Pair Dialog |  |
| InteractiveRouter | Drag45 Degree | D |
| InteractiveRouter | Drag Free Angle | G |
| InteractiveRouter | Highlight Mode |  |
| InteractiveRouter | Inline Drag |  |
| InteractiveRouter | Place Blind Via | Option+Shift+V |
| InteractiveRouter | Place Micro Via | Cmd+V |
| InteractiveRouter | Place Via | V |
| InteractiveRouter | Route Selected | Shift+X |
| InteractiveRouter | Route Selected From End | Shift+E |
| InteractiveRouter | Sel Layer And Place Blind Via | Option+< |
| InteractiveRouter | Sel Layer And Place Micro Via |  |
| InteractiveRouter | Sel Layer And Place Via | < |
| InteractiveRouter | Select Layer Pair |  |
| InteractiveRouter | Settings Dialog | Cmd+< |
| InteractiveRouter | Shove Mode |  |
| InteractiveRouter | Single Track | X |
| InteractiveRouter | Switch Posture | / |
| InteractiveRouter | Switch Rounding45 | Cmd+W |
| InteractiveRouter | Switch Rounding90 | Cmd+Option+W |
| InteractiveRouter | Switch Rounding Arc45 | Cmd+Shift+W |
| InteractiveRouter | Switch Rounding Arc90 | Option+W |
| InteractiveRouter | Switch Rounding To Next | Cmd+/ |
| InteractiveRouter | Undo Last Segment | Back |
| InteractiveRouter | Walkaround Mode |  |
| InteractiveSelection | Deselect Net |  |
| InteractiveSelection | Filter Selection |  |
| InteractiveSelection | Grab Unconnected | Shift+O |
| InteractiveSelection | Select Connection | U |
| InteractiveSelection | Select Net |  |
| InteractiveSelection | Select On Schematic |  |
| InteractiveSelection | Select On Sheet |  |
| InteractiveSelection | Select Same Sheet |  |
| InteractiveSelection | Select Unconnected | O |
| InteractiveSelection | Sync Selection |  |
| InteractiveSelection | Sync Selection With Nets |  |
| InteractiveSelection | Unroute Segment | Back |
| InteractiveSelection | Unroute Selected |  |
| LengthTuner | Settings | Cmd+L |
| LengthTuner | Tune Diff Pair | 8 |
| LengthTuner | Tune Diff Pair Skew | 9 |
| LengthTuner | Tune Single Track | 7 |
| MicrowaveTool | Create Function Shape |  |
| MicrowaveTool | Create Gap |  |
| MicrowaveTool | Create Line |  |
| MicrowaveTool | Create Stub |  |
| MicrowaveTool | Create Stub Arc |  |
| ModuleEditor | Check Footprint |  |
| ModuleEditor | Copy Footprint |  |
| ModuleEditor | Create Footprint |  |
| ModuleEditor | Cut Footprint |  |
| ModuleEditor | Delete Footprint |  |
| ModuleEditor | Duplicate Footprint |  |
| ModuleEditor | Edit Footprint |  |
| ModuleEditor | Export Footprint |  |
| ModuleEditor | Footprint Properties |  |
| ModuleEditor | Import Footprint |  |
| ModuleEditor | Load Footprint From Board |  |
| ModuleEditor | New Footprint | Cmd+N |
| ModuleEditor | Pad Table |  |
| ModuleEditor | Paste Footprint |  |
| ModuleEditor | Rename Footprint |  |
| ModuleEditor | Repair Footprint |  |
| ModuleEditor | Save Footprint To Board |  |
| Multichannel | Generate Placement Rule Areas |  |
| Multichannel | Repeat Layout |  |
| PadTool | Apply Pad Settings |  |
| PadTool | Copy Pad Settings |  |
| PadTool | Push Pad Settings |  |
| PadTool | Default Pad Properties |  |
| PadTool | Enumerate Pads |  |
| PadTool | Explode Pad | Cmd+E |
| PadTool | Place Pad |  |
| PadTool | Recombine Pad | Cmd+E |
| PcbDesignBlockControl | Delete Design Block |  |
| PcbDesignBlockControl | Edit Design Block Properties |  |
| PcbDesignBlockControl | Save Board As Design Block |  |
| PcbDesignBlockControl | Save Selection As Design Block |  |
| PcbDesignBlockControl | Show Design Block Panel |  |
| PcbDesignBlockControl | Update Design Block From Board |  |
| PcbDesignBlockControl | Update Design Block From Selection |  |
| Picker | Select Item Interactively |  |
| Picker | Select Point Interactively |  |
| PointEditor | Add Corner | F1 |
| PointEditor | Arc Keep Center |  |
| PointEditor | Arc Keep Endpoint |  |
| PointEditor | Arc Keep Radius |  |
| PointEditor | Chamfer Corner |  |
| PointEditor | Remove Corner |  |
| PositionRelative | Interactive Offset Tool |  |
| PositionRelative | Position Relative | Shift+P |
| ReannotateTool | Show Reannotate Dialog |  |
| ScriptingTool | Plugins Show Folder |  |
| TableEditor | Edit Table | Cmd+E |
| ZoneFiller | Zone Fill |  |
| ZoneFiller | Zone Fill All | B |
| ZoneFiller | Zone Fill Dirty |  |
| ZoneFiller | Zone Unfill |  |
| ZoneFiller | Zone Unfill All | Cmd+B |
| lengthTuner | Ampl Decrease | 4 |
| lengthTuner | Ampl Increase | 3 |
| lengthTuner | Spacing Decrease | 2 |
| lengthTuner | Spacing Increase | 1 |

## Page Layout Editor (plEditor)

| Context | Action | Shortcut |
|---|---|---|
| EditorControl | Layout Edit Mode |  |
| EditorControl | Layout Normal Mode |  |
| EditorControl | Preview Settings |  |
| EditorControl | Show Inspector |  |
| InteractiveDrawing | Draw Line |  |
| InteractiveDrawing | Draw Rectangle |  |
| InteractiveDrawing | Place Image |  |
| InteractiveDrawing | Place Text |  |
| InteractiveEdit | Append Worksheet |  |
| InteractiveMove | Move | M |

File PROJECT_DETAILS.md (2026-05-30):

# Arduino Nano ESP32 Carrier Board: Project Summary

## 1. Project Overview & Direction

The project is a custom printed circuit board (PCB) acting as a compact, feature-rich carrier/development board for the **Arduino Nano ESP32**. Designed to fit an approximate "iPhone footprint," it serves as an intermediate testing and prototyping platform bridging the gap between a bare breadboard and a full commercial development kit. The board exposes the Nano's GPIO to jumper headers while integrating a suite of robust, on-board peripherals for immediate physical computing, status indication, and sensor integration.

**Current State:** The schematic design is complete, logically verified, and fully annotated. All component footprints have been assigned, resolving pitch and symbol mismatches. The project is currently transitioning to the PCB layout and routing phase. Git version control has been initialized for cross-platform development.

---

## 2. Core Architecture & Power

* **Microcontroller:** Arduino Nano ESP32 (Dual-core, WiFi/Bluetooth capable).
* **Mounting:** Socket headers to seat the Nano ESP32, accompanied by parallel pin headers for standard jumper wire connectivity to external breadboards.
* **Power Rails:** On-board 5V (VUSB) and 3.3V rails accessible for peripheral and external development use.

---

## 3. Peripheral Specifications & Schematic Logic

Throughout the design phase, specific focus was placed on hardware-level safety ("student-proofing") and adherence to communication standards.

### Standard I/O

* **LEDs (x4):** Standard generic LEDs wired active-high with 1kΩ current-limiting resistors.
* **Push Buttons (x4):** Momentary tactile switches wired with standard 10kΩ pull-down resistors to ensure a clean `LOW` state when unpressed.

### Stateful Inputs (Toggle Switches)

* **Component:** SS12D00G-G3 (SPDT Slide Switches).
* **Logic:** Wired as state selectors without pull resistors (Pin 1 to 3.3V, Pin 3 to GND, Pin 2/Common to MCU). This provides a hard `HIGH` or `LOW` state.
* **Safety Integration:** A 1kΩ resistor is placed in series between the switch common and the ESP32 GPIO. This prevents a dead short (and blown pin) if the GPIO is accidentally programmed as an `OUTPUT LOW` while the switch is tied to 3.3V.
* *Note: Care must be taken to avoid utilizing the ESP32's strapping pins for these hard-wired switches.*

### I2C Expansion (Qwiic / STEMMA QT)

* **Component:** 4-pin JST-SH connector (1.0mm pitch).
* **Standard:** Follows the strict industry pinout: Pin 1 (GND), Pin 2 (3.3V), Pin 3 (SDA), Pin 4 (SCL).
* **Routing:** Explicitly mapped to the Arduino Nano ESP32 hardware I2C pins: **SDA to A4** and **SCL to A5**.
* **Logic:** Includes two 4.7kΩ pull-up resistors connecting SDA and SCL to the 3.3V rail to satisfy open-drain requirements.

### Analog Input

* **Component:** Alps RK09K 9mm Rotary Potentiometer.
* **Logic:** Wired as a safe voltage divider. Pin 1 to 3.3V, Pin 3 to GND, and Pin 2 (Wiper) routed to an Analog-capable pin (A0-A7).

### Addressable RGB Status LED

* **Component:** WS2812B (5050 form factor).
* **Power:** Fed directly from the 5V (VUSB) rail for stability, utilizing a 100nF decoupling capacitor placed physically close to the VDD/GND pins.
* **Data Line:** Driven by a 3.3V GPIO through a 470Ω series protection resistor. The DOUT pin is left unconnected, allowing for potential future chaining.

### Audio Debugging

* **Component:** 12mm Piezo Buzzer (PCB mount).
* **Hardware Mute:** An SS12D00 SPDT slide switch is placed in series with the buzzer signal.
* **Logic:** The switch connects the signal (buffered by a 220Ω resistor) to the buzzer's positive terminal in one position. In the mute position, the throw is left completely floating/unconnected to prevent unnecessary current drain to GND.

---

## 4. Footprint Assignments & CAD (KiCad) Resolutions

Several critical footprint and symbol discrepancies were caught and resolved prior to generating the netlist:

* **Switch Symbol Correction:** Replaced proprietary Wuerth switch symbols with generic `SW_SPDT` symbols in KiCad. This ensured that Pin 2 accurately represented the common pivot, preventing a catastrophic dead short between 3.3V and GND.
* **Switch Footprint Hack:** Assigned `PinHeader_1x03_P2.54mm_Vertical` to the slide switches to accommodate the 2.54mm pitch of the Amazon-sourced SS12D00G-G3 switches, ensuring a perfect fit without bent pins.
* **I2C Connector:** Assigned `JST_SH_SM04B-SRSS-TB_1x04-1MP_P1.00mm_Horizontal` (or Vertical).
* **Buzzer:** Assigned `Buzzer_12x9.5mm_CR2032_Vertical` to account for standard 7.62mm pitch through-hole mounting.
* **Potentiometer:** Assigned `Potentiometer_Alps_RK09K_Single_Vertical`, allowing for the 3 mono pins and 2 mechanical snap-in anchors.
* **Resistors:** Standardized based on physical inventory (THT `R_Axial_DIN0207...` vs. SMD `0603_HandSolder`).

---

## 5. Version Control Infrastructure

A Git repository has been initialized to allow seamless development between a primary PC and a MacBook Air.

* **Ignore Protocol:** A strict `.gitignore` is in place, specifically excluding KiCad's temporary files, backups (`*-bak`), lock files (`*.lck`), user-specific UI settings (`*.kicad_prl`), and the local footprint cache (`fp-info-cache`).
* **Workflow:** Development relies on a strict pull-before-opening, commit-after-closing loop to prevent merge conflicts in the binary-like CAD files.

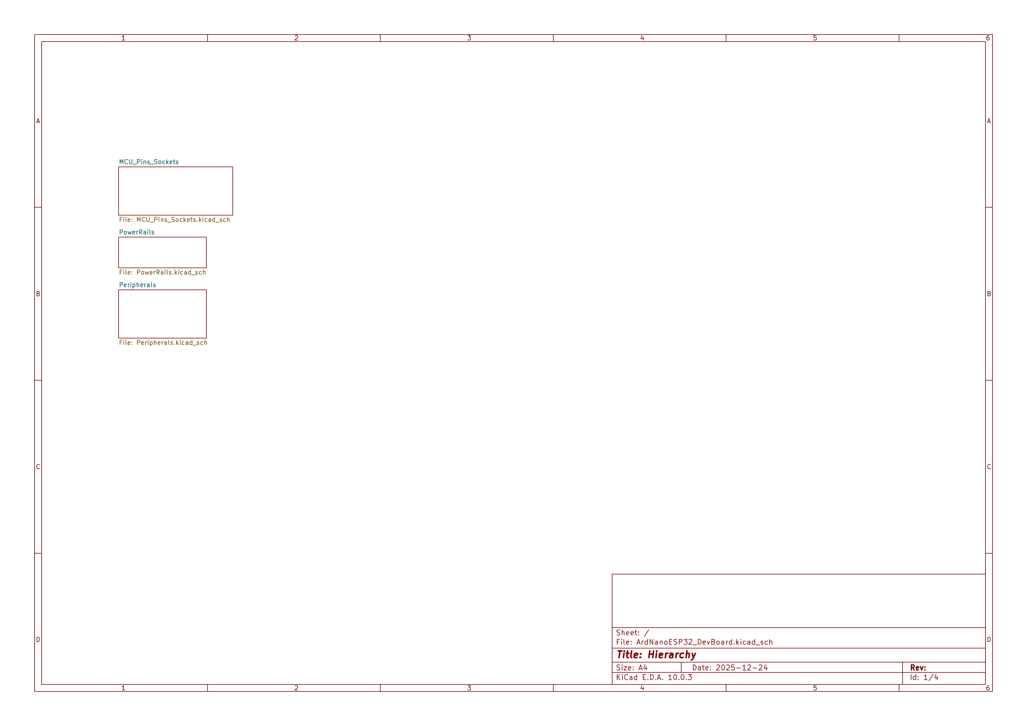
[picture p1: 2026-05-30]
schematics_captures/Hierarchy.png

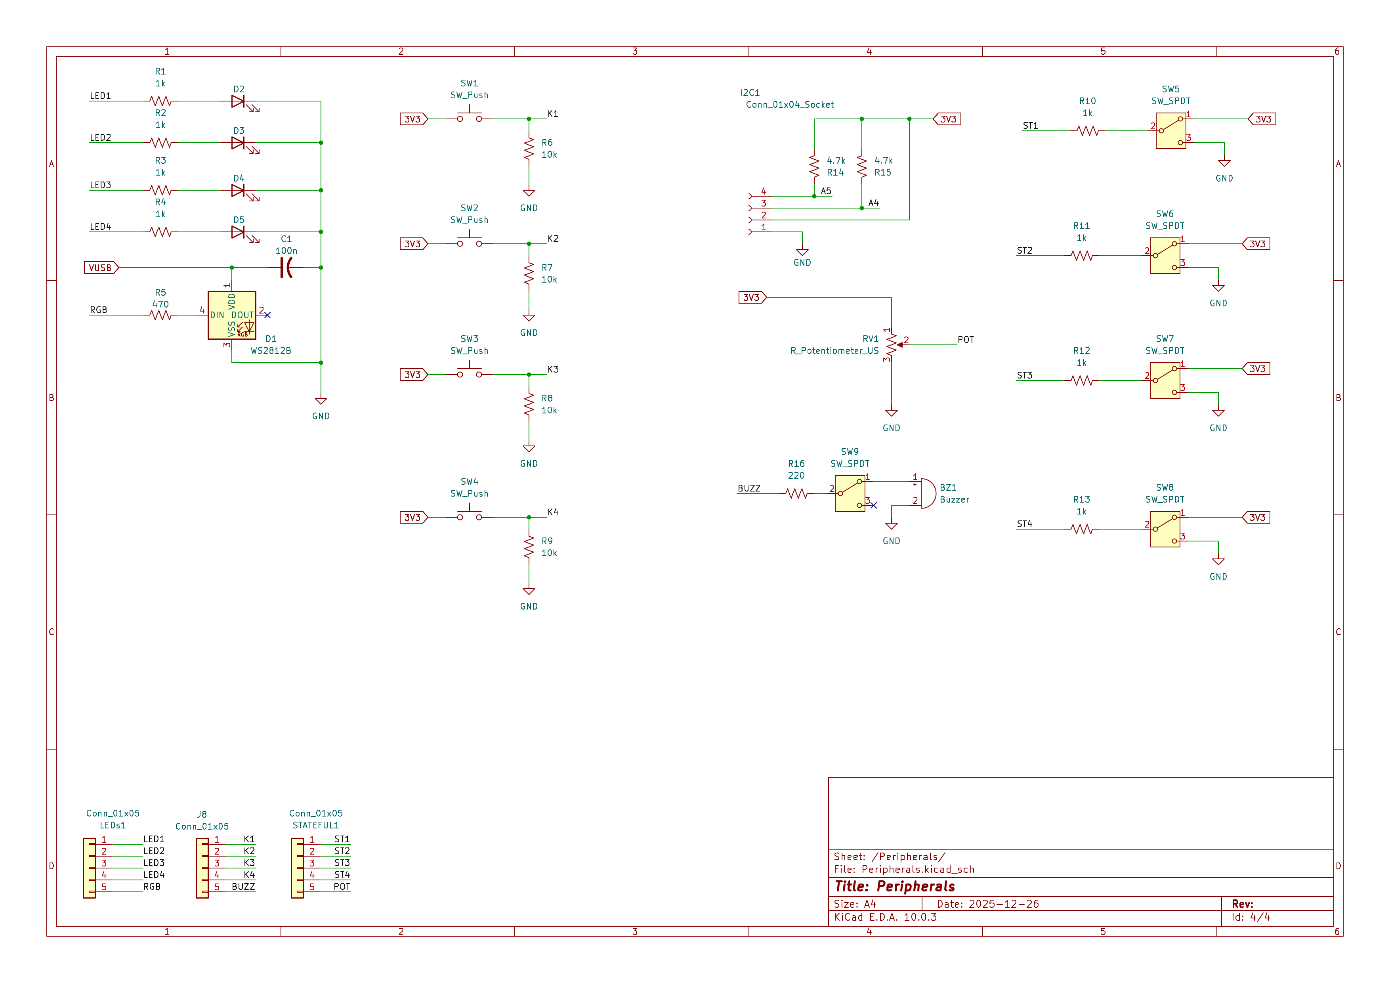
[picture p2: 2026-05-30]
schematics_captures/Peripherals.png

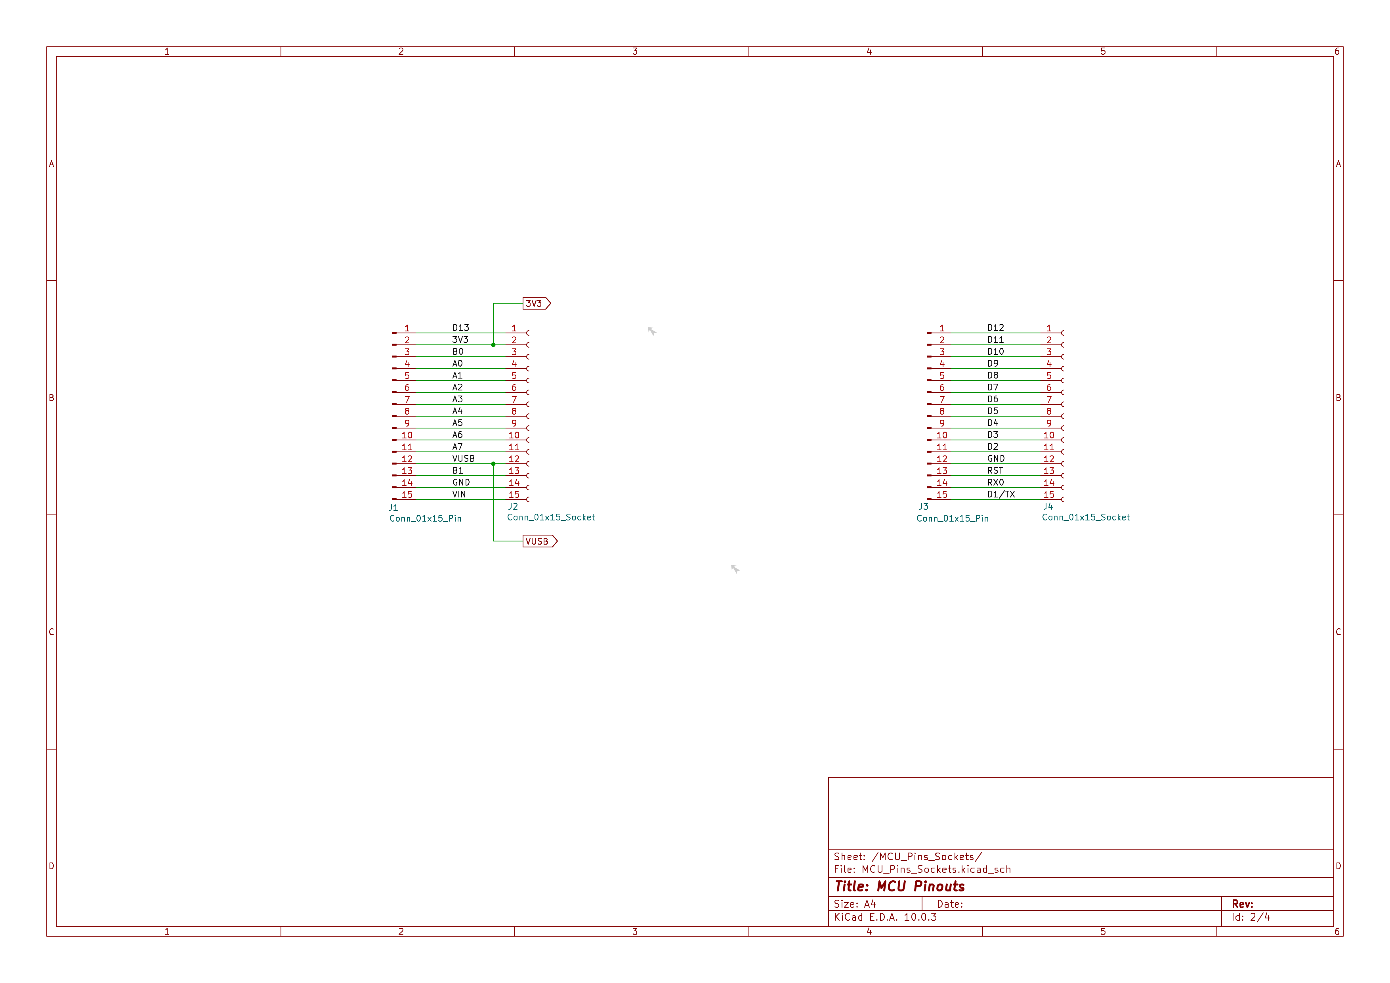
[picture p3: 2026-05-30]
schematics_captures/MCU pinouts.png

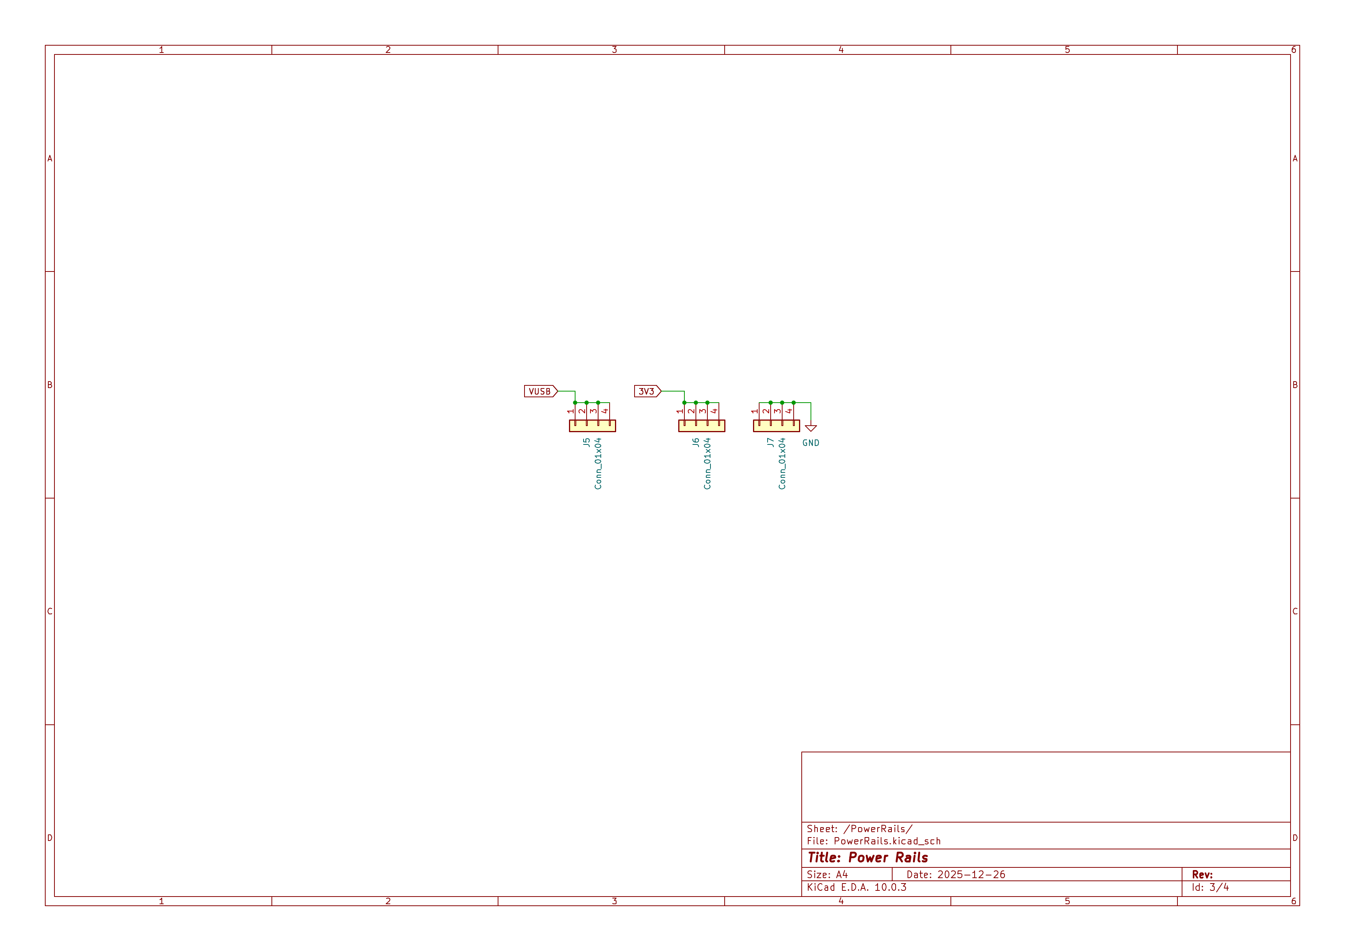
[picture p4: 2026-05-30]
schematics_captures/Power Rails.png

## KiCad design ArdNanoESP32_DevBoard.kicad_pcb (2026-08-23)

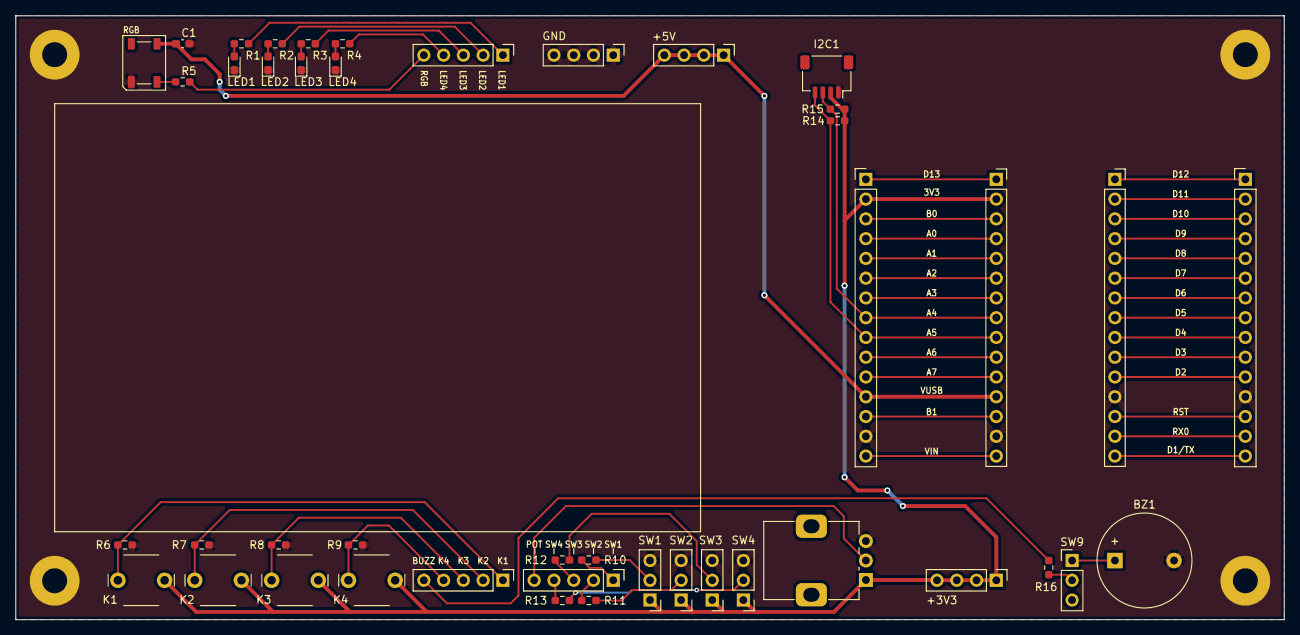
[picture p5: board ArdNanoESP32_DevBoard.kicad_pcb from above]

Board: 2 copper layers, 163.0 x 77.6 mm, 44 parts (0 on the bottom side), 55 nets.

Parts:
+3V3, +5V: Conn_01x04; PinHeader_1x04_P2.54mm_Vertical
BZ1: Buzzer; Buzzer_12x9.5RM7.6
C1: 100n; C_0603_1608Metric_Pad1.08x0.95mm_HandSolder
D1: WS2812B; LED_WS2812B_PLCC4_5.0x5.0mm_P3.2mm
GND: Conn_01x04; PinHeader_1x04_P2.54mm_Vertical
I2C1: Conn_01x04_Socket; JST_SH_SM04B-SRSS-TB_1x04-1MP_P1.00mm_Horizontal
J1, J3: Conn_01x15_Pin; PinHeader_1x15_P2.54mm_Vertical
J2, J4: Conn_01x15_Socket; PinSocket_1x15_P2.54mm_Vertical
J8: Conn_01x05; PinHeader_1x05_P2.54mm_Vertical
K1, K2, K3, K4: SW_Push; SW_PUSH_6mm_H5mm_CUSTOM
LED1, LED2, LED3, LED4: LED; LED_0603_1608Metric_Pad1.05x0.95mm_HandSolder
LEDs1: Conn_01x05; PinHeader_1x05_P2.54mm_Vertical
R1, R2, R3, R4, R10, R11, R12, R13: 1k; R_0603_1608Metric_Pad0.98x0.95mm_HandSolder
R5: 470; R_0603_1608Metric_Pad0.98x0.95mm_HandSolder
R6, R7, R8, R9: 10k; R_0603_1608Metric_Pad0.98x0.95mm_HandSolder
R14, R15: 4.7k; R_0603_1608Metric_Pad0.98x0.95mm_HandSolder
R16: 220; R_0603_1608Metric_Pad0.98x0.95mm_HandSolder
RV1: R_Potentiometer_US; Potentiometer_Alps_RK09K_Single_Vertical
STATEFUL1: Conn_01x05; PinHeader_1x05_P2.54mm_Vertical
SW1, SW2, SW3, SW4, SW9: SW_SPDT; PinHeader_1x03_P2.54mm_Vertical

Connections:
3V3: +3V3.1, +3V3.2, +3V3.3, +3V3.4, I2C1.2, J1.2, J2.2, K1.1, K2.1, K3.1, K4.1, R14.2, R15.2, RV1.1, SW1.1 (A), SW2.1 (A), SW3.1 (A), SW4.1 (A)
/MCU_Pins_Sockets/A0: J1.4, J2.4
/MCU_Pins_Sockets/A1: J1.5, J2.5
/MCU_Pins_Sockets/A2: J1.6, J2.6
/MCU_Pins_Sockets/A3: J1.7, J2.7
/MCU_Pins_Sockets/A6: J1.10, J2.10
/MCU_Pins_Sockets/A7: J1.11, J2.11
/MCU_Pins_Sockets/B0: J1.3, J2.3
/MCU_Pins_Sockets/B1: J1.13, J2.13
/MCU_Pins_Sockets/D1/TX: J3.15, J4.15
/MCU_Pins_Sockets/D2: J3.11, J4.11
/MCU_Pins_Sockets/D3: J3.10, J4.10
/MCU_Pins_Sockets/D4: J3.9, J4.9
/MCU_Pins_Sockets/D5: J3.8, J4.8
/MCU_Pins_Sockets/D6: J3.7, J4.7
/MCU_Pins_Sockets/D7: J3.6, J4.6
/MCU_Pins_Sockets/D8: J3.5, J4.5
/MCU_Pins_Sockets/D9: J3.4, J4.4
/MCU_Pins_Sockets/D10: J3.3, J4.3
/MCU_Pins_Sockets/D11: J3.2, J4.2
/MCU_Pins_Sockets/D12: J3.1, J4.1
/MCU_Pins_Sockets/D13: J1.1, J2.1
/MCU_Pins_Sockets/RST: J3.13, J4.13
/MCU_Pins_Sockets/RX0: J3.14, J4.14
/MCU_Pins_Sockets/VIN: J1.15, J2.15
/Peripherals/BUZZ: J8.5, R16.1
/Peripherals/BUZZ_ANODE: BZ1.1 (+), SW9.1 (A)
/Peripherals/K1: J8.1, K1.2, R6.1
/Peripherals/K2: J8.2, K2.2, R7.1
/Peripherals/K3: J8.3, K3.2, R8.1
/Peripherals/K4: J8.4, K4.2, R9.1
/Peripherals/LED1: LEDs1.1, R1.1
/Peripherals/LED1_ANODE: LED1.2 (A), R1.2
/Peripherals/LED2: LEDs1.2, R2.1
/Peripherals/LED2_ANODE: LED2.2 (A), R2.2
/Peripherals/LED3: LEDs1.3, R3.1
/Peripherals/LED3_ANODE: LED3.2 (A), R3.2
/Peripherals/LED4: LEDs1.4, R4.1
/Peripherals/LED4_ANODE: LED4.2 (A), R4.2
/Peripherals/POT: RV1.2, STATEFUL1.5
/Peripherals/RGB: LEDs1.5, R5.1
/Peripherals/RGB_ANODE: D1.4 (DIN), R5.2
/Peripherals/ST1: R10.1, STATEFUL1.1
/Peripherals/ST2: R11.1, STATEFUL1.2
/Peripherals/ST3: R12.1, STATEFUL1.3
/Peripherals/ST4: R13.1, STATEFUL1.4
/Peripherals/SW1_COM: R10.2, SW1.2 (B)
/Peripherals/SW2_COM: R11.2, SW2.2 (B)
/Peripherals/SW3_COM: R12.2, SW3.2 (B)
/Peripherals/SW4_COM: R13.2, SW4.2 (B)
/Peripherals/SW9_COM: R16.2, SW9.2 (B)
A4: I2C1.3, J1.8, J2.8, R15.1
A5: I2C1.4, J1.9, J2.9, R14.1
GND: BZ1.2 (-), C1.2, D1.3 (VSS), GND.1, GND.2, GND.3, GND.4, I2C1.1, J1.14, J2.14, J3.12, J4.12, LED1.1 (K), LED2.1 (K), LED3.1 (K), LED4.1 (K), R6.2, R7.2, R8.2, R9.2, RV1.3, SW1.3 (C), SW2.3 (C), SW3.3 (C), SW4.3 (C)
VUSB: +5V.1, +5V.2, +5V.3, +5V.4, C1.1, D1.1 (VDD), J1.12, J2.12

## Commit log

2026-05-30 Schematic captures of different peripherals and pinouts
2026-05-30 Markdown files featuring projet details and kicad shortcuts on macos for use with Claude AI
2026-05-30 - added global nets for A4 and A5
    - I2C connetor changes
    - Throw swtiches and button identifiers changed
    [ArdNanoESP32_DevBoard.kicad_sch, MCU_Pins_Sockets.kicad_sch, Peripherals.kicad_sch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]
2026-05-30 New custom Arduino Nano ESP32 outline footprint for guiding / dimension purposes
2026-05-30 PCB additions and placement of pinheaders and half-size breadboard
    [ArdNanoESP32_DevBoard.kicad_pcb]
2026-08-23 peripheral changes
    [MCU_Pins_Sockets.kicad_sch]
2026-08-23 some other changes
    [Peripherals.kicad_sch, PowerRails.kicad_sch]
2026-08-23 the rest lol
    [ArdNanoESP32_DevBoard-B_Cu.gbl, ArdNanoESP32_DevBoard-B_Mask.gbs, ArdNanoESP32_DevBoard-Edge_Cuts.gm1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]
